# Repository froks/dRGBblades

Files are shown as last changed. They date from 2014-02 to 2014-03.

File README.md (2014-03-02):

dRGBblades
==========

dRGBblades is a small pcb to drive a lpd8806-based led stripe on a rc-helicopter blade with a 1s lipo

It consists of a DC/DC-converter that converts the 1s lipo input voltage (3.3-4.2V) to a 5V/2A output
to power the led stripe and a atmel attiny84 to control the digital side of the stripe.

The DC/DC-converter is based on a LT3436 (http://cds.linear.com/docs/en/datasheet/3436fa.pdf) switching
regulator.

dRGBblades on a voodoo 600 installed on radix 600mm blades:
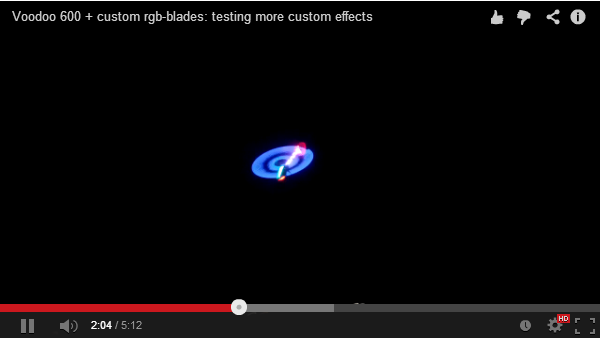
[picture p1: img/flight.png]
voodoo 600 demo fligth (http://www.youtube.com/watch?v=HWoczqaCDM8)


dRGBblades stripe only test video:
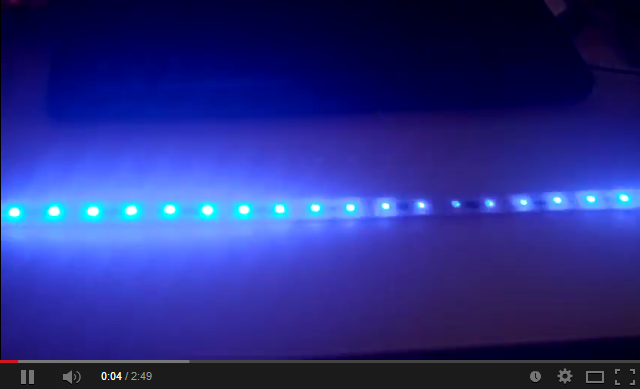
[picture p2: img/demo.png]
stripe test video (http://www.youtube.com/watch?v=5hTq98XmnZc)


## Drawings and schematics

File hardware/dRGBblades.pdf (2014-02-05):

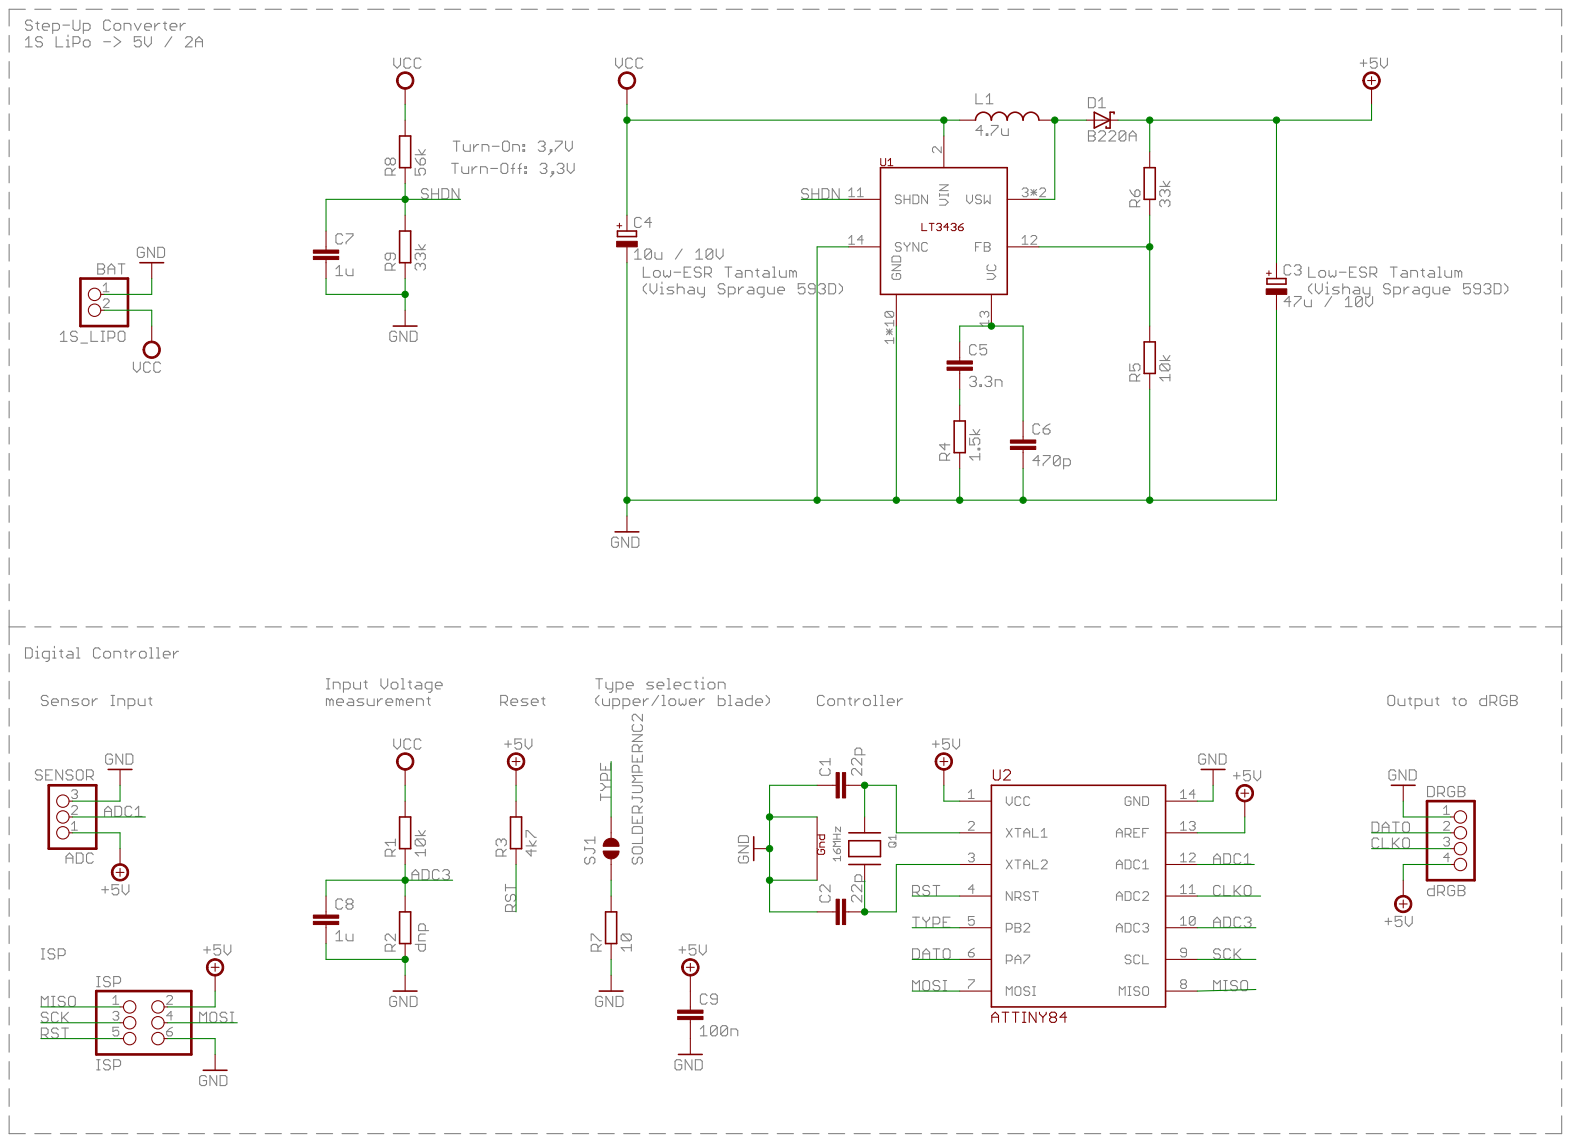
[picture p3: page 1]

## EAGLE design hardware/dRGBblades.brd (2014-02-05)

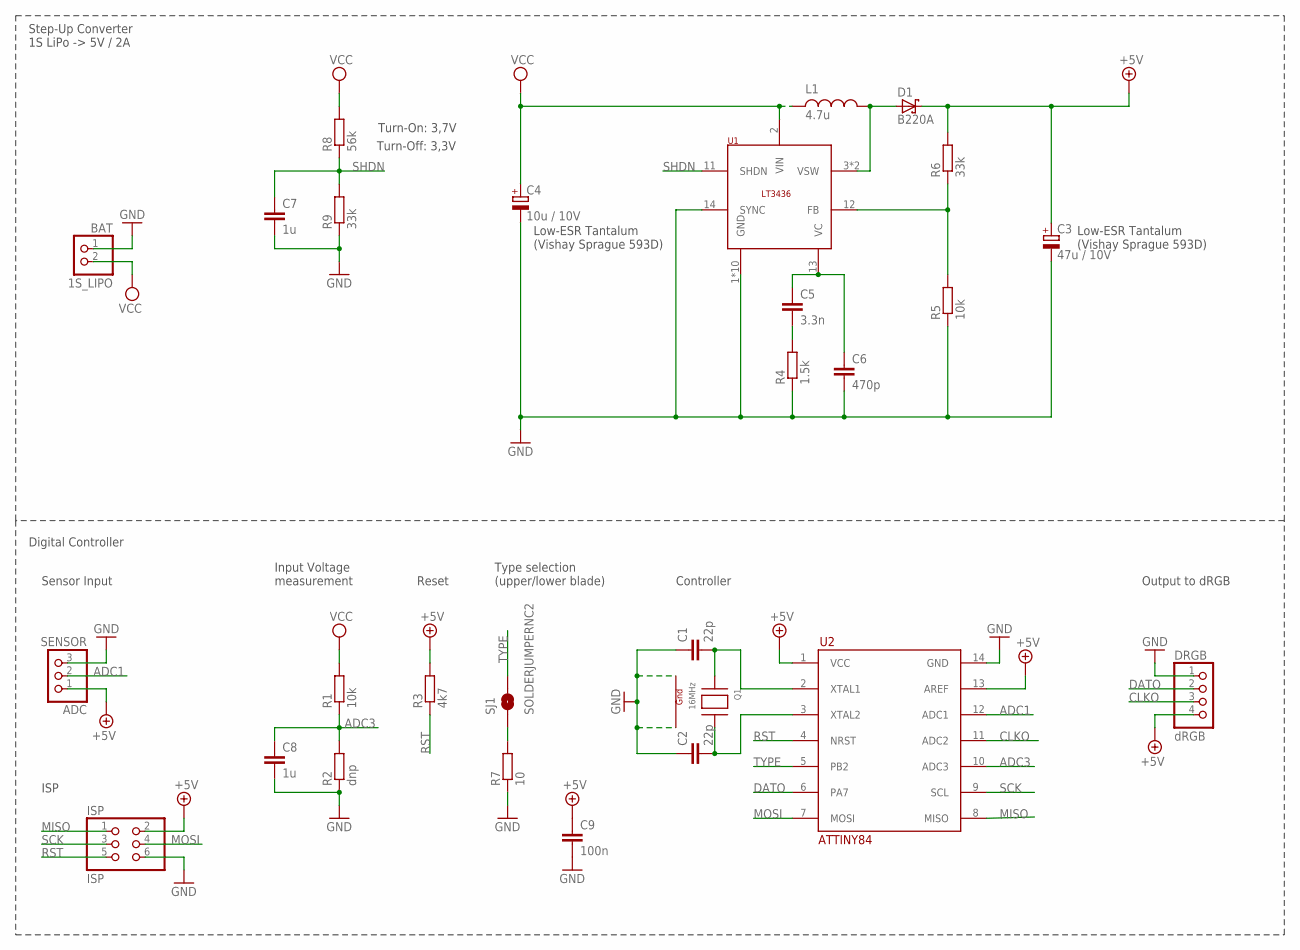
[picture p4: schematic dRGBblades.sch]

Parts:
ADC: SENSOR; 1X03/90
BAT: 1S_LIPO; 1X02/90
C1, C2: 22p; C0603
C3: 47u / 10V; D/7343-31W
C4: 10u / 10V; A/3216-18W
C5: 3.3n; C0603
C6: 470p; C0603
C7, C8: 1u; C0603
C9: 100n; C0603
D1: B220A; SMA
DRGB: dRGB; 1X04/90
ISP: ISP; 2X03/90
L1: 4.7u; INDUCTOR-SUMIDA-CDRH6
Q1: 16MHz; NX3225
R1, R5: 10k; R0603
R2: dnp; R0603
R3: 4k7; R0603
R4: 1.5k; R0603
R6, R9: 33k; R0603
R7: 10; R0603
R8: 56k; R0603
SJ1: SOLDERJUMPERNC2; SJ_2S-NOTRACE
U1: LT3436; TSSOP-17
U2: ATTINY84; SO14

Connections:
+5V: ADC.1, C3.+, C9.1, D1.C, DRGB.4, ISP.2, R3.2, R6.2, U2.1 (VCC), U2.13 (AREF)
ADC1: ADC.2, U2.12 (ADC1)
ADC3: C8.1, R1.1, R2.2, U2.10 (ADC3)
CLKO: DRGB.3, U2.11 (ADC2)
DATO: DRGB.2, U2.6 (PA7)
GND: ADC.3, BAT.1, C1.1, C2.1, C3.-, C4.-, C6.2, C7.2, C8.2, C9.2, DRGB.1, ISP.6, Q1.2 (G2), Q1.4 (G1), R2.1, R4.1, R5.1, R7.1, R9.1, U1.1 (GND), U1.5 (GND), U1.6 (GND), U1.7 (GND), U1.8 (GND), U1.9 (GND), U1.10 (GND), U1.14 (SYNC), U1.15 (GND), U1.16 (GND), U1.17 (GND), U2.14 (GND)
MISO: ISP.1, U2.8 (MISO)
MOSI: ISP.4, U2.7 (MOSI)
unnamed: C5.1, C6.1, U1.13 (VC)
unnamed: C2.2, Q1.3 (X2), U2.3 (XTAL2)
unnamed: C1.2, Q1.1 (X1), U2.2 (XTAL1)
unnamed: C5.2, R4.2
unnamed: D1.A, L1.P$2, U1.3 (VSW), U1.4 (VSW)
unnamed: R5.2, R6.1, U1.12 (FB)
unnamed: R7.2, SJ1.1
RST: ISP.5, R3.1, U2.4 (NRST)
SCK: ISP.3, U2.9 (SCL)
SHDN: C7.1, R8.1, R9.2, U1.11 (SHDN)
TYPE: SJ1.2, U2.5 (PB2)
VCC: BAT.2, C4.+, L1.P$1, R1.2, R8.2, U1.2 (VIN)

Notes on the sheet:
Low-ESR Tantalum (Vishay Sprague 593D)
Digital Controller
Sensor Input
ISP
Input Voltage measurement
Reset
Type selection (upper/lower blade)
Controller
Output to dRGB
Turn-On: 3,7V
Turn-Off: 3,3V
Step-Up Converter 1S LiPo -> 5V / 2A

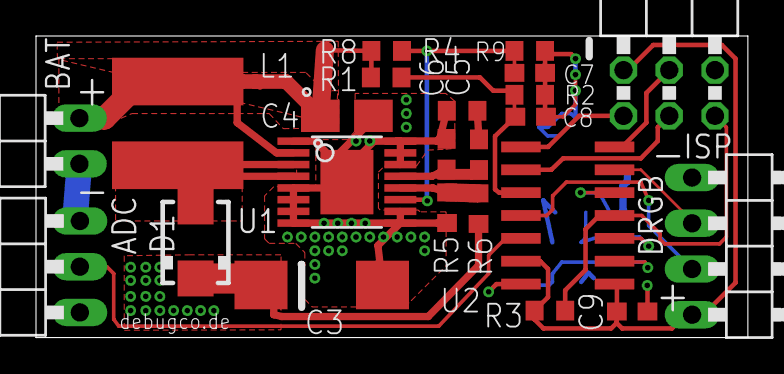
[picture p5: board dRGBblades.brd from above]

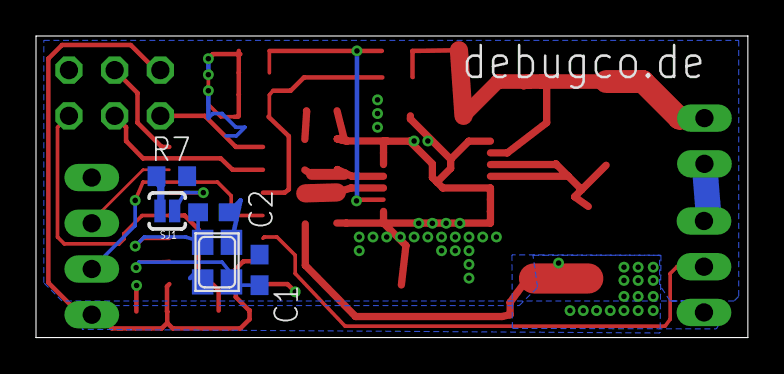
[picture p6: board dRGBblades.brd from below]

Board: 2 copper layers, 39.5 x 16.8 mm, 28 parts (5 on the bottom side), 20 nets.

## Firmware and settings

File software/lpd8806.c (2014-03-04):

#include "lpd8806.h"

uint8_t *pixels = NULL;
uint8_t *effectswitchpixels = NULL;
volatile uint8_t effectchangeactive = 0;
volatile uint8_t alphablend = 0;

uint16_t num_leds;
uint16_t num_bytes;
uint16_t num_latchbytes;

#define DATAPIN (1 << PA7)
#define CLKPIN (1 << PA2)

// Adapted from LPD8806-Arduino library

void lpd8806_init(void)
{
	// PA2 = CLK, PA7 = DATA
	DDRA = CLKPIN | DATAPIN; // USCK / MOSI = OUTPUT
}

void lpd8806_set_length(uint16_t n)
{
	if (pixels != NULL)	{
		free(pixels);
	}
    if (effectswitchpixels != NULL) {
        free(effectswitchpixels);
    }
    
	
	num_leds = n;
	num_latchbytes = ((num_leds + 31) / 32);
	num_bytes = (num_leds * 3) + num_latchbytes;
	if (NULL != (pixels = malloc(num_bytes)))
	{
		memset(pixels, 0x80, num_leds * 3);
		memset(&pixels[num_leds * 3], 0, num_latchbytes);
	}
	else
	{
		num_bytes = 0;
		num_leds = 0;
	}
	
    if (NULL != (effectswitchpixels = malloc(num_bytes)))
	{
    	memset(effectswitchpixels, 0x80, num_leds * 3);
    	memset(&effectswitchpixels[num_leds * 3], 0, num_latchbytes);
	}
}

void lpd8806_start(void)
{
	PORTA &= ~DATAPIN;
	uint8_t i;
	for (i = ((num_leds+31)/32)*8; i > 0; --i) {
      PORTA |=  CLKPIN;
      PORTA &= ~CLKPIN;
    }	
	
	for (i = num_leds; i > 0; --i)
	{
		lpd8806_set_pixel(i, 0, 0, 0);
	}
	lpd8806_update_strip();
}

uint16_t lpd8806_get_length(void)
{
	return num_leds;
}

// colors 0-127
void lpd8806_set_pixel(uint16_t n, uint8_t r, uint8_t g, uint8_t b)
{
	if (n >= num_leds) {
		return;
	}
	
	uint8_t *ptr = &pixels[n * 3];
	*ptr++ = r | 0x80;
	*ptr++ = g | 0x80;
	*ptr++ = b | 0x80;
}

void lpd8806_set_pixel_rgb(uint16_t n, uint32_t c)
{
	if (n >= num_leds) {
		return;
	}
	
	uint8_t *ptr = &pixels[n * 3];
	*ptr++ = (c >> 16) | 0x80;
	*ptr++ = (c >> 8) | 0x80;
	*ptr++ = (c) | 0x80;
}


void lpd8806_update_strip(void)
{
	for (uint8_t i = 0; i < num_bytes; ++i)	{
		// Data = PA7
		// Clock = PA2
		uint8_t data = *&pixels[i];
        if (effectchangeactive == 1 && alphablend > 0 && i < (num_bytes - num_latchbytes)) {
    		uint16_t dataeffectchange = (*&effectswitchpixels[i]) & 0x7F;
            uint16_t v = data & 0x7F;
            v *= (128 - alphablend);
            v += (dataeffectchange * alphablend);
            v /= 128;
            data = 0x80 | v; 
        }
        
		for (uint8_t bit = 0x80; bit; bit >>= 1) {
			// Set Data Pin
			if (data & bit) {
				PORTA |= DATAPIN;
			} else {
				PORTA &= ~DATAPIN;
			}
			// Toggle clock
			PORTA |= CLKPIN;
			PORTA &= ~CLKPIN;
		}
	}
}

void lpd8806_starteffect(void)
{
/*    if (effectchangeactive == 1) {
        // TODO 
    } */
    memcpy(effectswitchpixels, pixels, num_bytes);
    effectchangeactive = 1;
    alphablend = 128;
}

void lpd8806_effects_isr()
{
    if (effectchangeactive == 1) {
        if (alphablend > 3) {
            alphablend -= 3;
        } else {
            alphablend = 0;
            effectchangeactive = 0;
        }
    }        
}

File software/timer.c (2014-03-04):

#include "timer.h"
#include "init.h"
#include "effects.h"

#include <avr/interrupt.h>

#include "lpd8806.h"

volatile uint16_t seconds_since_start = 0;
volatile uint8_t undervoltage = 0;
volatile uint8_t timer_overflow_counter = 0;
volatile uint16_t adcinavg = 0;
volatile uint8_t adcincount = 0;


void setup_adc(void)
{
	// Use Vcc as Voltage reference, PA3 single ended input
	ADMUX = _BV(MUX1) | _BV(MUX0); 
	
	// ADLAR - left adjust the result
//	ADCSRB = (1 << ADLAR);

	// ADCN (ADC Enable), ADSC (ADC Start Conversion), Prescale Clock / 64
	// _BV(ADPS2) | _BV(ADPS1) | _BV(ADPS0); 
	ADCSRA = _BV(ADPS2) | _BV(ADPS1) | _BV(ADPS0); 
	ADCSRA = _BV(ADEN) | _BV(ADSC) | _BV(ADATE);
}

volatile uint8_t ddd = 0;

void check_adc(void)
{
	uint16_t adcin = ((ADCH << 8) | ADCL) & 0x3FF;
	// 0-1024 = 0 - 5V1; adcvalue = (vin * 1024) / 5.1
	adcinavg += adcin;
	adcincount += 1;
	
	if (adcincount >= 10)
	{
		uint32_t avg = (adcinavg / adcincount);

		if (avg < 750)
		{
			undervoltage = 1;
		}
		adcinavg = 0;
		adcincount = 0;
	}
	
	if (undervoltage > 0)
	{
		cli();
		while (true)
		{
			if (is_top())
			{
				low_battery_lights(127, 0, 0);
			}
			else
			{
				low_battery_lights(0, 127, 0);
			}
		}
	}
}

void setup_timer(void)
{
	setup_adc();
	// Prescale / 1024 (8000000 / 1024 = 7812,5 interrupts per second / 256 = 30 overflows per second for ADC-Checks and elapsed seconds timer
	TCCR0B |= _BV(CS02) | _BV(CS00);
	TIMSK0 |= _BV(TOIE0);
    
	// Prescale / 8 (8000000 / 1 = 8000000 interrupts per second / 65536 = 122 overflows per second for alpha-blending effects
    TCCR1B |= _BV(CS00);
    TIMSK1 |= _BV(TOIE0);
    
	sei();
}

inline uint16_t elapsed_seconds()
{
	return seconds_since_start;
}

ISR(TIM0_OVF_vect)
{
	if ((timer_overflow_counter % 5) == 0)
	{
		check_adc();
	}
			
	if (++timer_overflow_counter >= 30)  
	{
		timer_overflow_counter = 0;
		++seconds_since_start;
	}
}

ISR(TIM1_OVF_vect)
{
    lpd8806_effects_isr();
}

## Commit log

2014-02-05 hardware files initial commit
    [dRGBblades.brd, dRGBblades.sch]
2014-02-07 massive size optimization some bugfixes
    [lpd8806.c]
2014-02-07 added a ~1sec timer and second counter

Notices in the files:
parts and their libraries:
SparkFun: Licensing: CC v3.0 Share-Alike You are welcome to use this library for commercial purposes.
